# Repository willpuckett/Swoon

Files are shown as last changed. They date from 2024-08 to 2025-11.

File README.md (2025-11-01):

# Swoon Half Xiao'd

> Yet another diode matrix rework of the
> [Ferris Sweep Half Swept](https://github.com/davidphilipbarr/Sweep/tree/main/Sweep%20half-swept)
> for
> [Seeed Xiao nRF52840](https://www.seeedstudio.com/Seeed-XIAO-BLE-nRF52840-p-5201.html).

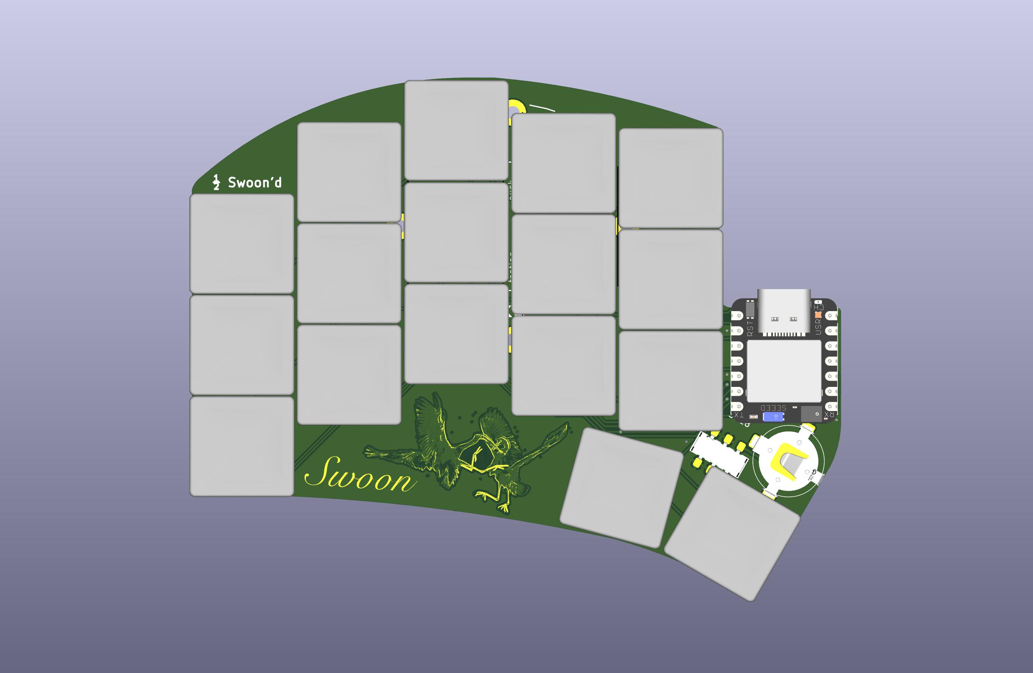
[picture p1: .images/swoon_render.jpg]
Swoon Half Xiao'd


## Motivations

- Utilise Seeed Xiao—it's cuter
- Experiment with parts consignment for PCBA of hotswaps
- Choose a battery that can be easily changed by users who do not solder
  (LIR1254)
- Explore using CI/CD for board variants, case, and top plate generation
- Locate each half's components on its respective top side for more affordable
  assembly and lower overall height

> [!NOTE]
> In a Hurry? Here are the relevant links for download. No need scroll...
>
> Boards [[flip](/jlcpcb/swoon_FLIP.zip)] [[left](/jlcpcb/swoon_LEFT.zip)]
> [[right](/jlcpcb/swoon_RIGHT.zip)] [[both](/jlcpcb/swoon_BOTH.zip)]
>
> Case
> [[step](https://nightly.link/willpuckett/Swoon/actions/runs/10987780383/Case_STEP.zip)]
> [[stl](https://nightly.link/willpuckett/Swoon/actions/runs/10987780383/Case_STL.zip)]
>
> Firmware
> [[latest ZMK Builds](https://nightly.link/willpuckett/Swoon/workflows/zmk/main/swoon.zip)]

## Variants

[^1]

### **Flip**

> [!IMPORTANT]
> You'll need to solder the upward facing jumpers on each half under the Xiao
> before use.

A flippable variant [[flip](/jlcpcb/swoon_FLIP.zip)] for hand-soldering, like
the original half-swept. **Flip** is also the most cost conscious variant—about
$7.60 to get 5 of the boards produced, enough for 2 full keyboads and a nice...
coaster?

> [!CAUTION]
> Use 3.7v LIR1254 (lithium ion rechargable) battery **only**.

#### BOM

| QTY | Part | JLCPCB Part # |
| :---: | :---: | :---: |
| 2 | 0906-2-15-20-75-14-11-0 | C5261048 |
| 2 | BAT-SMD_MY-LR44-02 | C2902345 |
| 4 | 310-13-107-41-001000 or MF254V-11-07-0743 | C5504401 |
| 68 (optional) | 3305-0-15-80-47-27-10-0 | C17370797 |
| 2 | MST22D18G2125 | C2906280 |
| 34 | CD4148WS (or 1N4148 SOD-323 from Amazon)  | C38587762 |
| 34 | Your ChocV1 switches of choice | N/A |
| 2 | 3.7V LIR1254 (NOT LR44!) | N/A |

### **Left** and **Right**

These variants are designed to be produced and assembled by JLCPCB. Each zip
file [[left](/jlcpcb/swoon_LEFT.zip)] [[right](/jlcpcb/swoon_RIGHT.zip)] has the
a gerbers/drill zip, a cpl, and bom file. They should be fully assemblable, but
you'll need to preorder the parts through global sourcing before paying. The
3305s aren't cheap and they cost extra to assemble.

Each half is pre-jumpered in the gerbers so you can print and go.

> [!CAUTION]
> Use 3.7v LIR1254 (lithium ion rechargable) battery **only**.

There's also a [[both](/jlcpcb/swoon_BOTH.zip)] that will probably supersede the
**left** and **right** since it's cheaper to produce as a single piece.

## Case



There's a case
[[step](https://nightly.link/willpuckett/Swoon/actions/runs/10987780383/Case_STEP.zip)]
[[stl](https://nightly.link/willpuckett/Swoon/actions/runs/10987780383/Case_STL.zip)]
that's really more of a skin. Print and place the pcb directly in it.

> [!TIP]
> Polymaker TPU works well. It seems to like to print slow and cool—leave the
> door open.

TPU is relatively non-slip, and it absorbs and distributes the force of typing
very nicely, so no bumpons needed which further reduces height.

## Layouts




Download the
[latest ZMK Builds](https://nightly.link/willpuckett/Swoon/workflows/zmk/main/swoon.zip).
The link contains the following layouts...

### QWERTY

QWERTY

### Engram

Engram

### Engrammer

Engrammer

[^1]: This project is mostly setup for production and assembly variants in
    GitHub actions. ~~Production variants are newer to KiCad and there's still a
    few kinks, but hopefully they'll be worked out soon.~~ The KiBot team has
    resolved the issues this project will pull them in for a release shortly. In
    the mean time, use the files in the [jlcpcb](/jlcpcb/) directory.

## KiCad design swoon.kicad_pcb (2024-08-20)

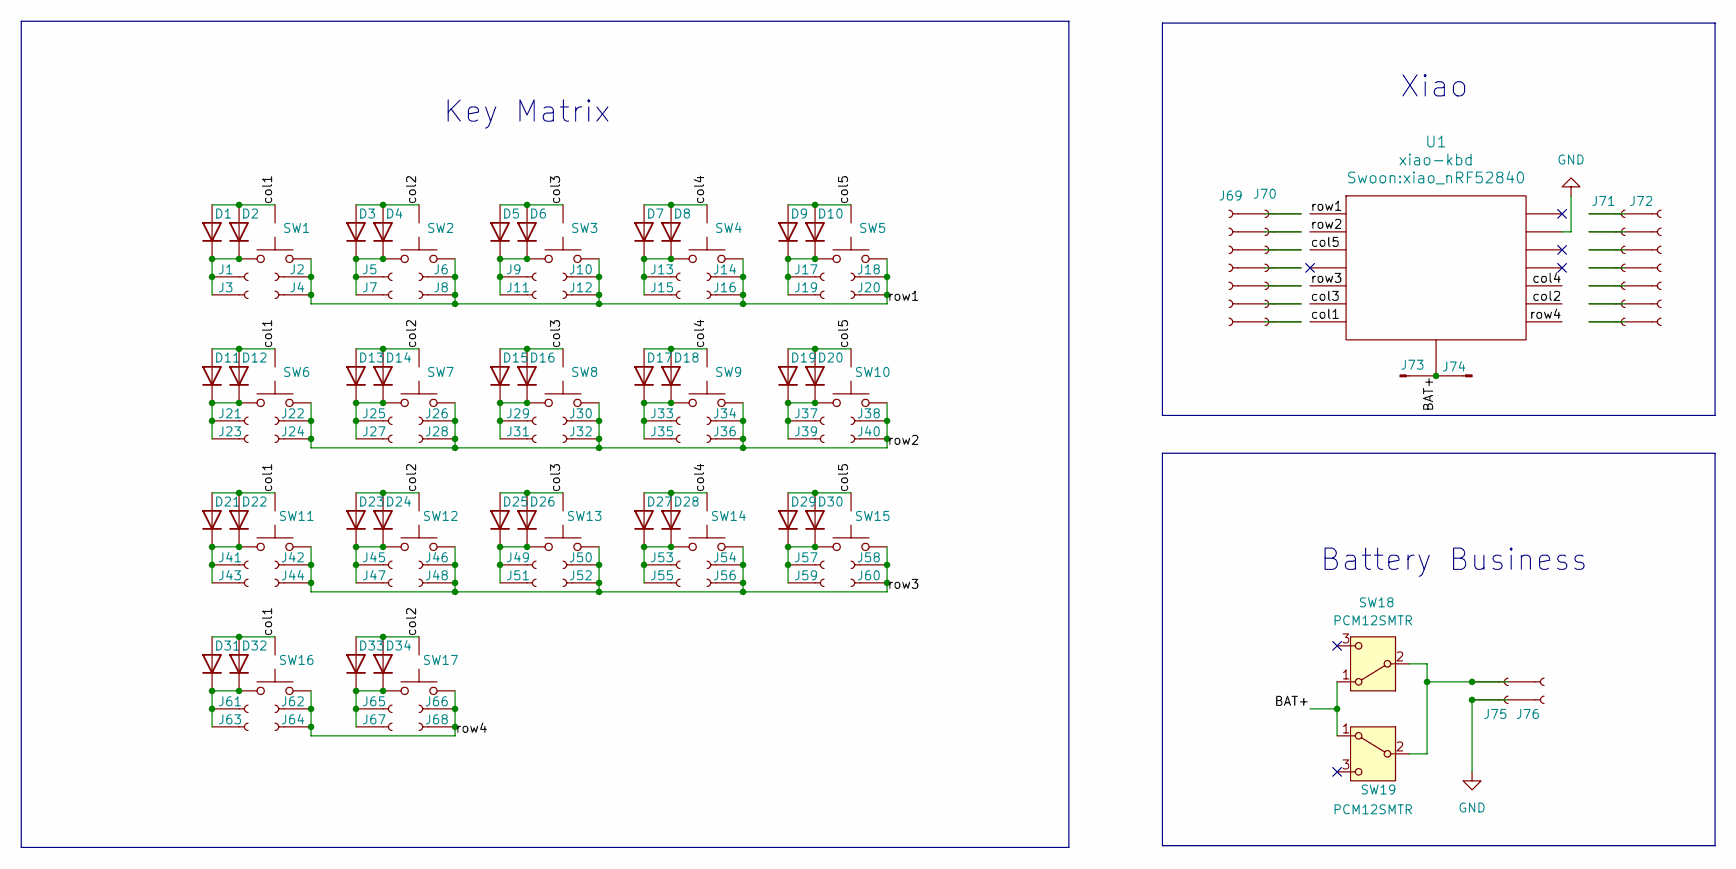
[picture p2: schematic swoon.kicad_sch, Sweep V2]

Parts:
D1, D2, D3, D4, D5, D6, D7, D8, D9, D10, D11, D12, D13, D14, D15, D16, D17, D18, D19, D20, D21, D22, D23, D24, D25, D26, D27, D28, D29, D30, D31, D32, D33, D34: CD4148WSP-C109001; D_0805_2012Metric
J1, J2, J3, J4, J5, J6, J7, J8, J9, J10, J11, J12, J13, J14, J15, J16, J17, J18, J19, J20, J21, J22, J23, J24, J25, J26, J27, J28, J29, J30, J31, J32, J33, J34, J35, J36, J37, J38, J39, J40, J41, J42, J43, J44, J45, J46, J47, J48, J49, J50, J51, J52, J53, J54, J55, J56, J57, J58, J59, J60, J61, J62, J63, J64, J65, J66, J67, J68: 3305-0-15-80-47-27-10-0
J69, J70, J71, J72: MF254V-11-07-0743
J73, J74: Mill Max 0906-2-15-20-75-14-11-0; 0906-2-15-20-75-14-11-0
J75, J76: JST SM02B-SRSS-TB(LF)(SN); JST_SH_SM02B-SRSS-TB_1x02-1MP_P1.00mm_Horizontal
SW1, SW2, SW3, SW4, SW5, SW6, SW7, SW8, SW9, SW10, SW11, SW12, SW13, SW14, SW15, SW16, SW17: SW_Push; SW_PG1350_vias
SW18, SW19: PCM12SMTR; SW_PCM12SMTR
U1: xiao-kbd; xiao_nRF52840

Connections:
/BAT+: J73.1, J74.1, SW18.1 (A), SW19.1 (A), U1.15 (BAT+)
/col1: D1.2 (A), D2.2 (A), D11.2 (A), D12.2 (A), D21.2 (A), D22.2 (A), D31.2 (A), D32.2 (A), SW1.3, SW6.3, SW11.3, SW16.3, U1.7 (D6)
/col2: D3.2 (A), D4.2 (A), D13.2 (A), D14.2 (A), D23.2 (A), D24.2 (A), D33.2 (A), D34.2 (A), SW2.3, SW7.3, SW12.3, SW17.3, U1.9 (D8)
/col3: D5.2 (A), D6.2 (A), D15.2 (A), D16.2 (A), D25.2 (A), D26.2 (A), SW3.3, SW8.3, SW13.3, U1.6 (D5)
/col4: D7.2 (A), D8.2 (A), D17.2 (A), D18.2 (A), D27.2 (A), D28.2 (A), SW4.3, SW9.3, SW14.3, U1.10 (D9)
/col5: D9.2 (A), D10.2 (A), D19.2 (A), D20.2 (A), D29.2 (A), D30.2 (A), SW5.3, SW10.3, SW15.3, U1.3 (D2)
/row1: J2.1, J4.1, J6.1, J8.1, J10.1, J12.1, J14.1, J16.1, J18.1, J20.1, SW1.1, SW2.1, SW3.1, SW4.1, SW5.1, U1.1 (D0)
/row2: J22.1, J24.1, J26.1, J28.1, J30.1, J32.1, J34.1, J36.1, J38.1, J40.1, SW6.1, SW7.1, SW8.1, SW9.1, SW10.1, U1.2 (D1)
/row3: J42.1, J44.1, J46.1, J48.1, J50.1, J52.1, J54.1, J56.1, J58.1, J60.1, SW11.1, SW12.1, SW13.1, SW14.1, SW15.1, U1.5 (D4)
/row4: J62.1, J64.1, J66.1, J68.1, SW16.1, SW17.1, U1.8 (D7)
GND: J75.1, J76.1, U1.13 (GND)
unnamed: D1.1 (K), D2.1 (K), J1.1, J3.1, SW1.2
unnamed: D3.1 (K), D4.1 (K), J5.1, J7.1, SW2.2
unnamed: D5.1 (K), D6.1 (K), J9.1, J11.1, SW3.2
unnamed: D7.1 (K), D8.1 (K), J13.1, J15.1, SW4.2
unnamed: D9.1 (K), D10.1 (K), J17.1, J19.1, SW5.2
unnamed: D11.1 (K), D12.1 (K), J21.1, J23.1, SW6.2
unnamed: D13.1 (K), D14.1 (K), J25.1, J27.1, SW7.2
unnamed: D15.1 (K), D16.1 (K), J29.1, J31.1, SW8.2
unnamed: D17.1 (K), D18.1 (K), J33.1, J35.1, SW9.2
unnamed: D19.1 (K), D20.1 (K), J37.1, J39.1, SW10.2
unnamed: D21.1 (K), D22.1 (K), J41.1, J43.1, SW11.2
unnamed: D23.1 (K), D24.1 (K), J45.1, J47.1, SW12.2
unnamed: D25.1 (K), D26.1 (K), J49.1, J51.1, SW13.2
unnamed: D27.1 (K), D28.1 (K), J53.1, J55.1, SW14.2
unnamed: D29.1 (K), D30.1 (K), J57.1, J59.1, SW15.2
unnamed: D31.1 (K), D32.1 (K), J61.1, J63.1, SW16.2
unnamed: D33.1 (K), D34.1 (K), J65.1, J67.1, SW17.2
unnamed: J69.1, J70.1
unnamed: J69.2, J70.2
unnamed: J69.3, J70.3
unnamed: J69.4, J70.4
unnamed: J69.5, J70.5
unnamed: J69.6, J70.6
unnamed: J69.7, J70.7
unnamed: J71.1, J72.1
unnamed: J71.2, J72.2
unnamed: J71.3, J72.3
unnamed: J71.4, J72.4
unnamed: J71.5, J72.5
unnamed: J71.6, J72.6
unnamed: J71.7, J72.7
unnamed: J75.2, J76.2, SW18.2 (B), SW19.2 (B)

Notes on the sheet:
Battery Business
Key Matrix
Xiao

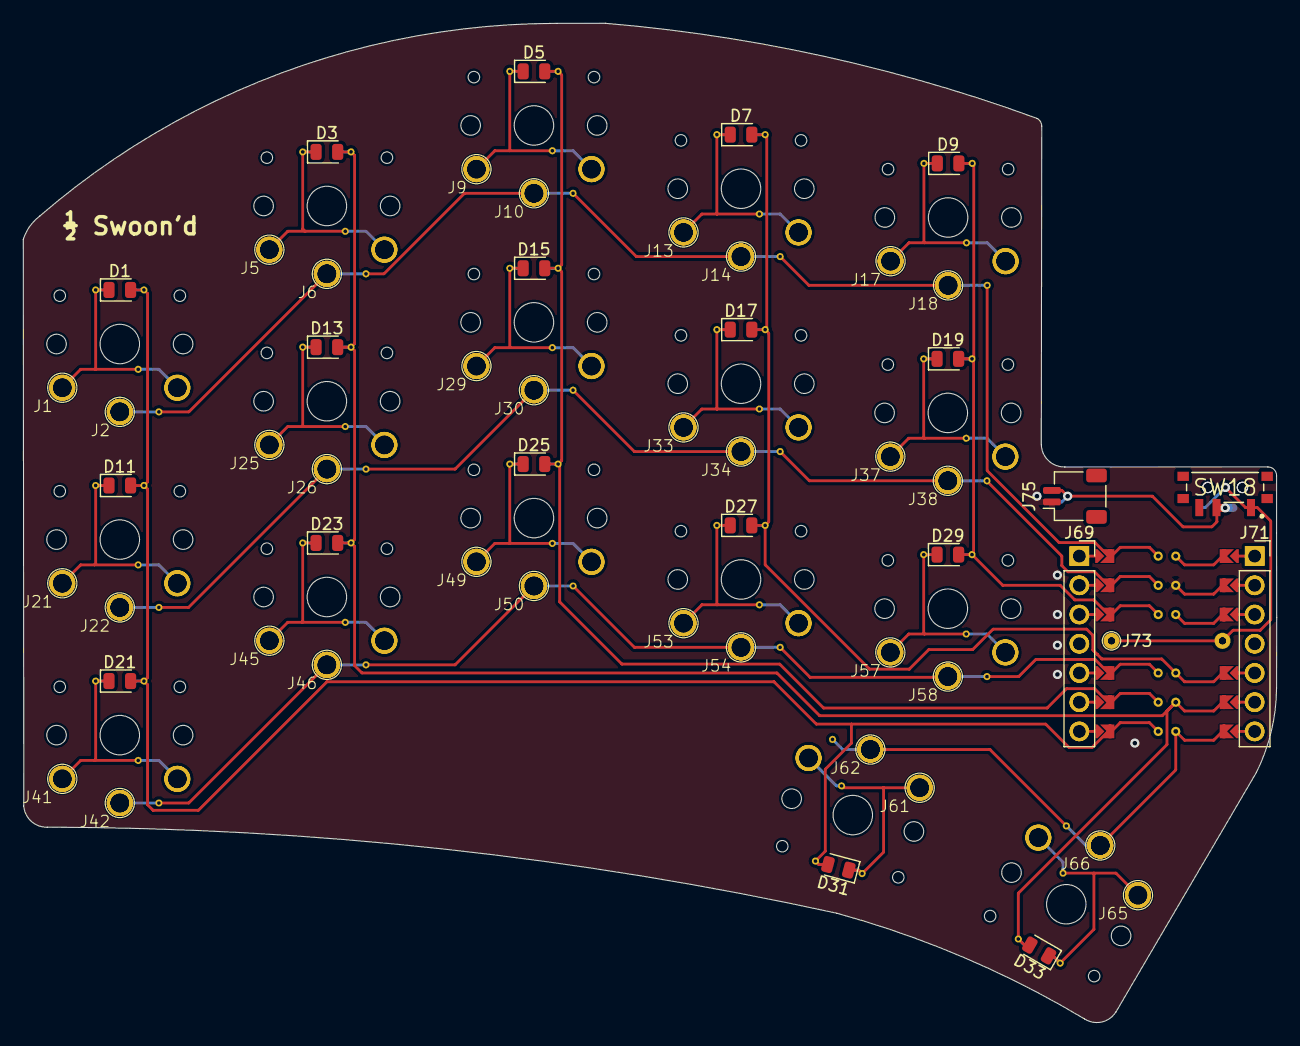
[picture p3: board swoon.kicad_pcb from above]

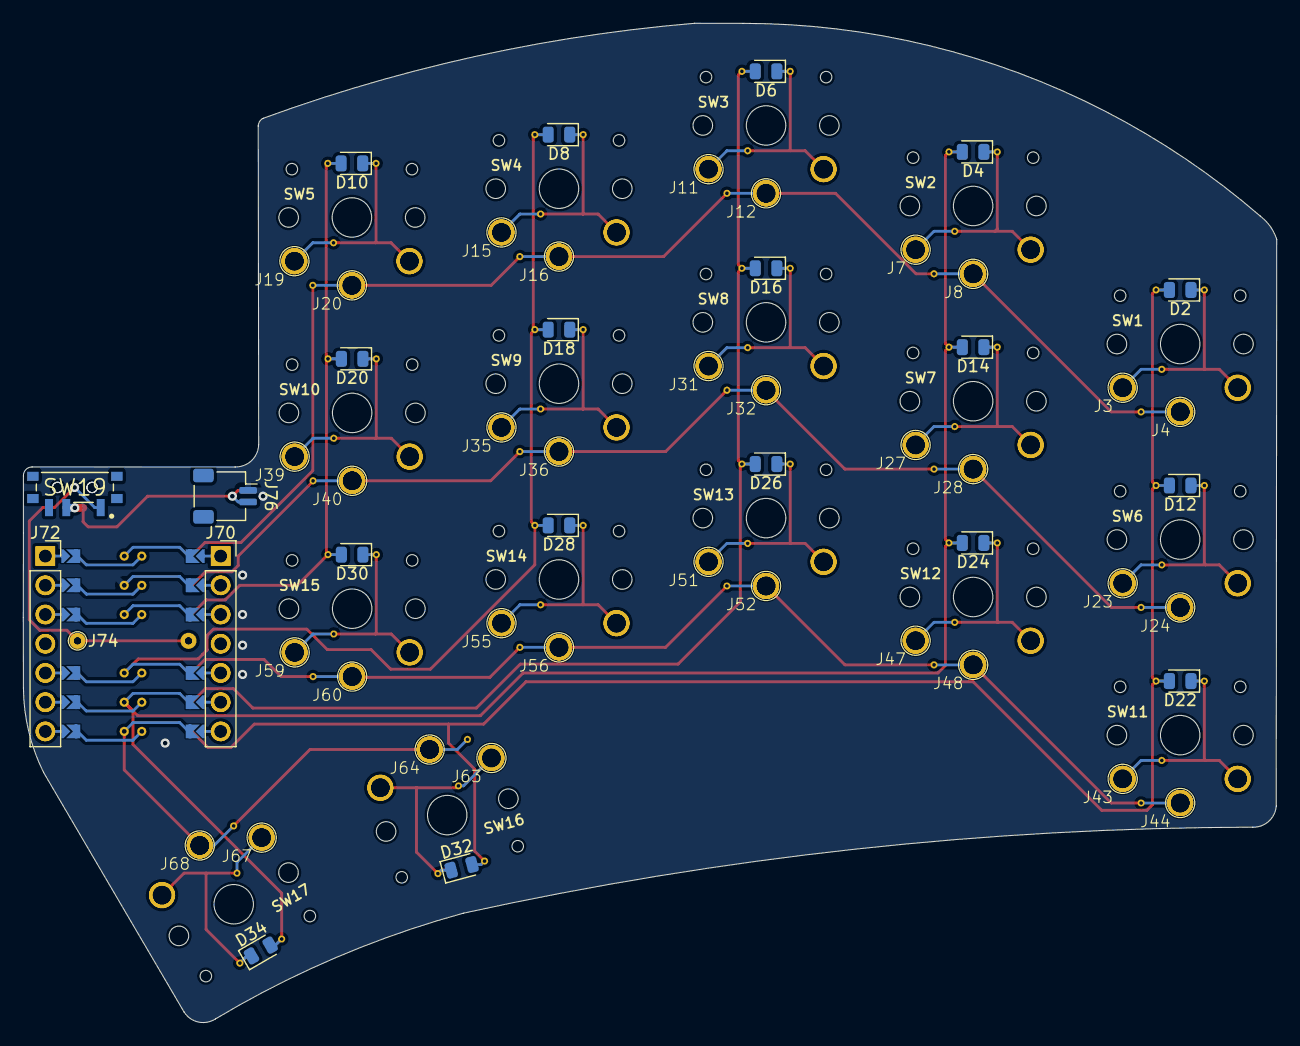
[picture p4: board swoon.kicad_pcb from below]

Board: 2 copper layers, 109.0 x 86.9 mm, 130 parts (56 on the bottom side), 43 nets.

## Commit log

2024-08-20 position battery terminal & power switch
    [swoon.kicad_pcb, swoon.kicad_sch]
2024-08-21 add tenting puck, copper graphic
    [swoon.kicad_sch]
2024-08-21 update production files
    [BOM-swoon.csv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]
2024-09-06 add kicad action
    [swoon.kicad_sch]
2024-09-06 add kibot file
    [BOM-swoon.csv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]
2024-09-07 add variants
    [swoon.kicad_sch]
2024-09-08 add rotataed variant
    [swoon.kicad_sch]
2024-09-08 add mpn field
    [swoon.kicad_sch]
2024-09-08 fix mp errors
    [swoon.kicad_sch]
2024-09-09 add devcontainer
    [swoon.kicad_sch]
2024-09-09 organize devcontainer
    [swoon.kicad_sch]
2024-09-09 fix testpads, update kibot.yaml
    [swoon.kicad_sch]
2024-09-12 place origins for svg
    [case.step]
2024-09-12 add case action
    [case.step]
2024-09-13 erroring var_rename stuff
    [swoon.kicad_sch]
2024-09-20 fix 3d models
    [swoon.kicad_sch]
2024-09-20 using drill files from flip in left and right variants
2024-09-20 correct edge cuts and schematic globs
2024-09-20 change board outline and archive names
2024-09-20 update pcb
2024-09-20 clean up
    [swoon.kicad_sch]
2024-09-22 add zips of Flip, Left, and Right variants
    [case.step, case.stl, swoon.kicad_sch]
2024-09-23 add build123d workflow
    [swoon.kicad_sch]
2024-09-23 Revert "add build123d workflow"
    This reverts commit e4690586cedccb0c1d963ceafc7b9e119b231d94.
    [swoon.kicad_sch]
2024-09-23 test case action without artifact
2024-09-23 evolve case.yml
2024-09-23 zudgeing case
2024-09-23 reroute switches
    [swoon.kicad_sch]
